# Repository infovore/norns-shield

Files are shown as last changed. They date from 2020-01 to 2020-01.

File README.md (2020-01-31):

# norns-shield



minimal/tiny open-source/DIY shield for Raspberry Pi boards, providing hardware compatibility with the [norns](monome.org/norns) ecosystem.

- audio codec: CS4720
- audio jacks: 3.5mm stereo in/out, line level
- OLED: NHD-2.7-12864WDW3
- 3x pushbuttons, 3x rotary encoders

see the full [BOM on Octopart](https://octopart.com/bom-tool/Q3rQej3x)

see [https://llllllll.co/t/diy-norns-shield](https://llllllll.co/t/diy-norns-shield/27638) for discussion.

[monome.org](https://monome.org)

SMD-populated PCB available from [monome.org](https://market.monome.org)

**200131 update:** tip/ring on audio IO are now swapped around. This will make
left/right work as per the default, out of the box Norns image.

If you are using an older shield than 200131, and want to reverse the audio routing
such that panning works correctly, place an empty file called `reverse.txt` in the
home directory on your norns. (Eg: SSH into norns, and type `touch
reverse.txt`). Restart the norns engines from the UI, and you should have
correct routing.





## assembly

for SMD-populated circuit.

parts shown (header already soldered to OLED)



first solder the OLED header. then the encoders, and keys.





then attach the pi header to the other side and solder as shown.



attach the screen to the top.

check the forum thread above for the newest disk image.

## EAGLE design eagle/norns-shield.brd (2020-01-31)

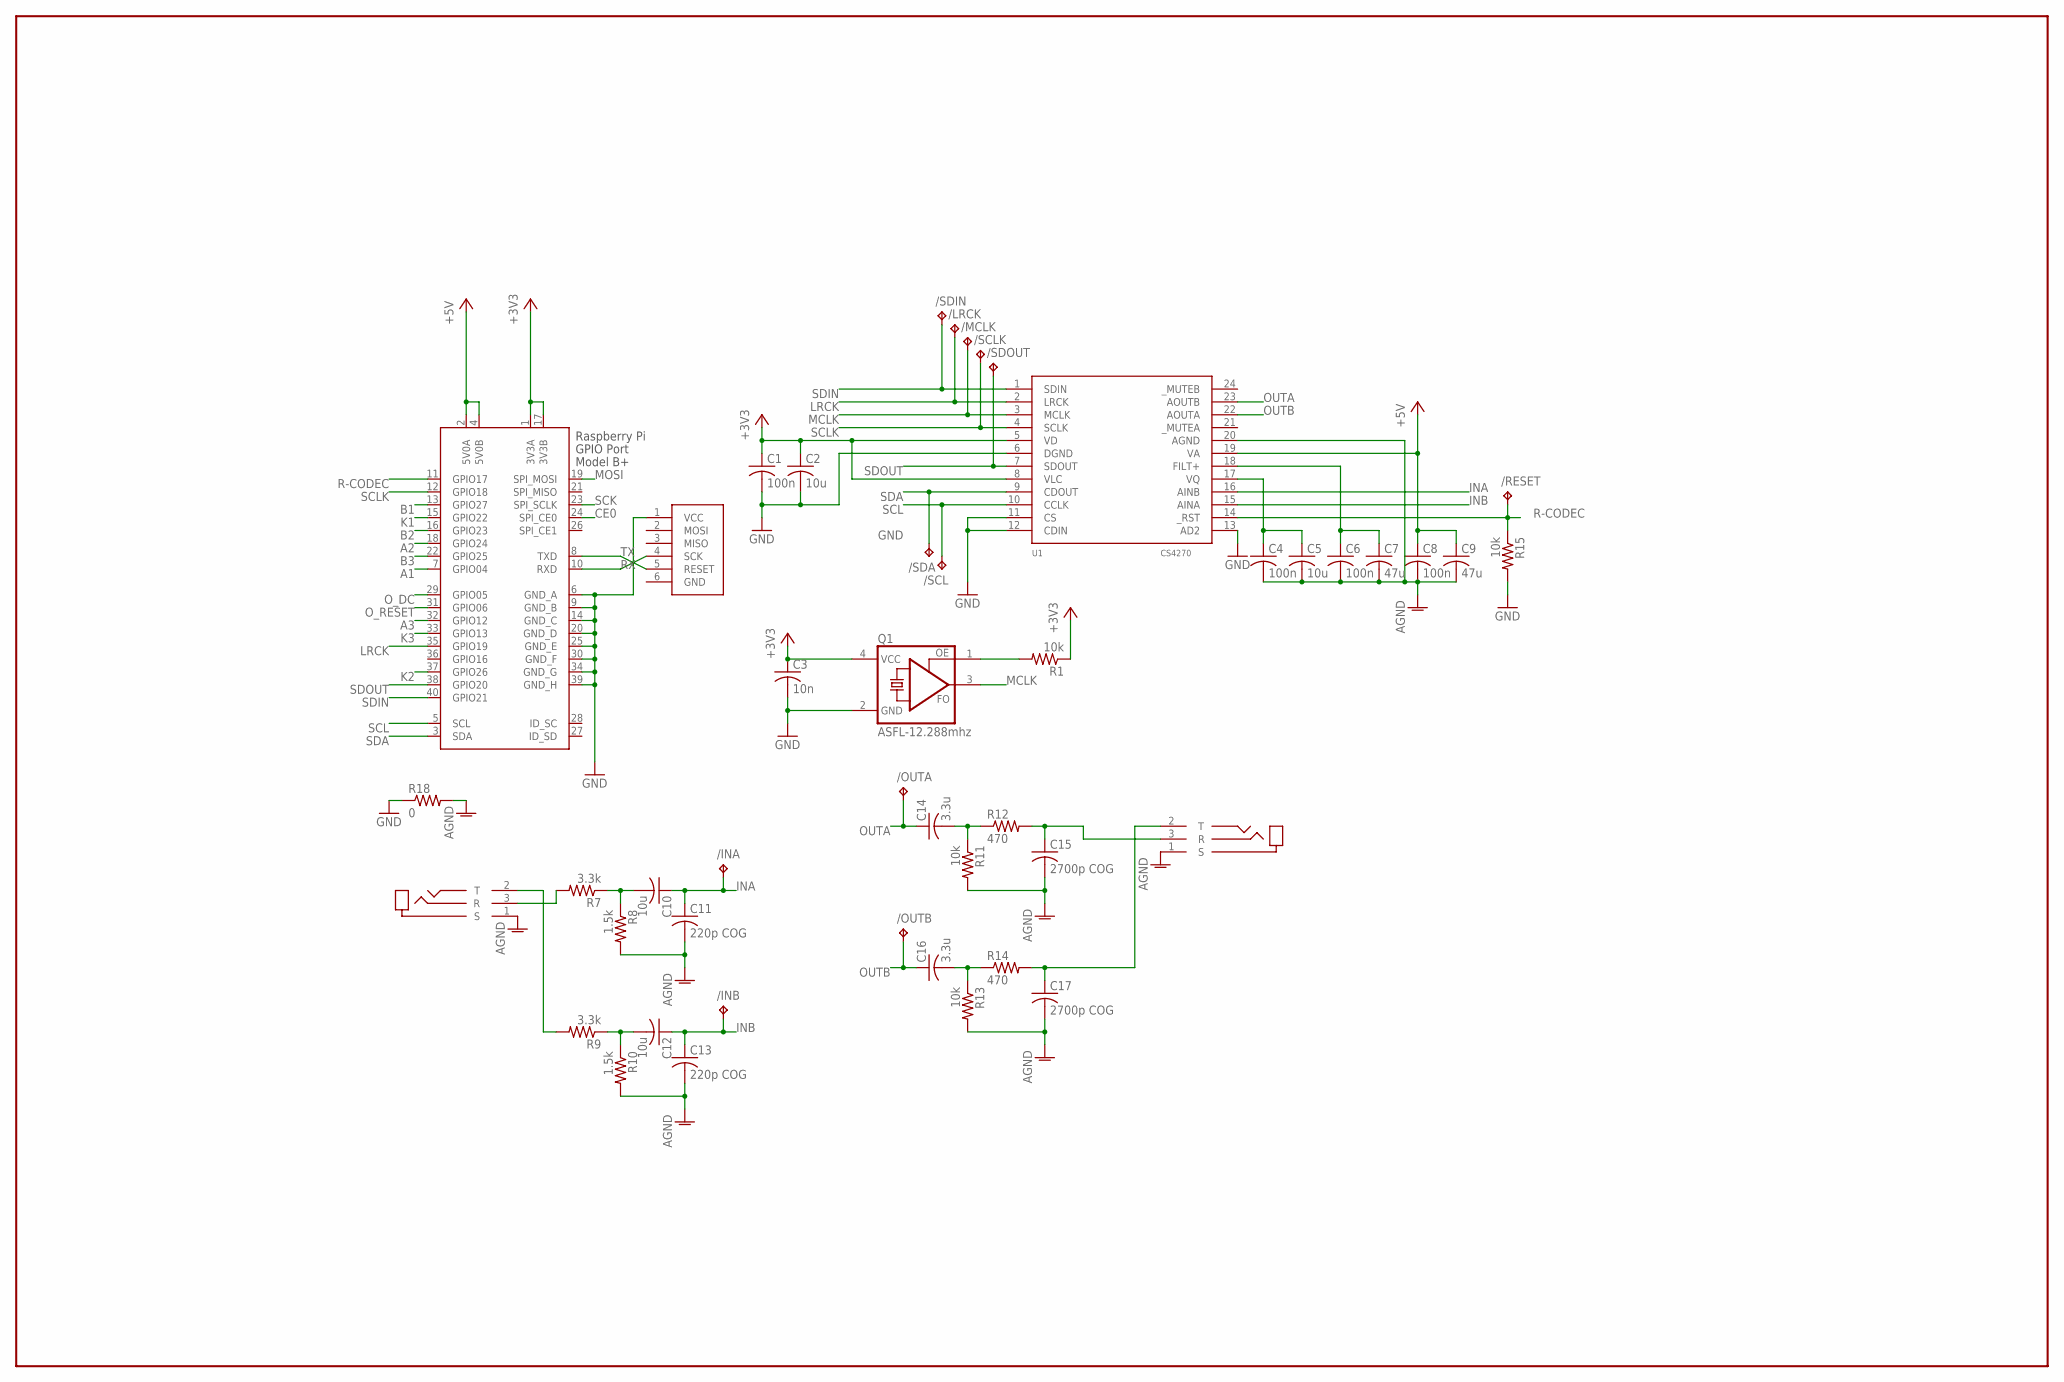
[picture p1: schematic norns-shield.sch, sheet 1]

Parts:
/INA: TPTP12R; TP12R
/INB: TPTP12R; TP12R
/LRCK: TPTP12R; TP12R
/MCLK: TPTP12R; TP12R
/OUTA: TPTP12R; TP12R
/OUTB: TPTP12R; TP12R
/RESET: TPTP12R; TP12R
/SCL: TPTP12R; TP12R
/SCLK: TPTP12R; TP12R
/SDA: TPTP12R; TP12R
/SDIN: TPTP12R; TP12R
/SDOUT: TPTP12R; TP12R
C1, C4, C6, C8: 100n; C0603
C2, C5, C10, C12: 10u; C0805
C3: 10n; C0603
C7, C9: 47u; C1206
C11, C13: 220p COG; C0603
C14, C16: 3.3u; C0805
C15, C17: 2700p COG; C0603
J1: TRS-IN; SJ-3523-SMT
J2: TRS-OUT; SJ-3523-SMT
J3: ISP-ROW
Q1: ASFL-12.288mhz; ASF
R1, R11, R13, R15: 10k; R0603
R7, R9: 3.3k; R0603
R8, R10: 1.5k; R0603
R12, R14: 470; R0603
R18: 0; R0603
U1: CS4270; TSSOP24
X1: RASPI_BOARD_B+#_E3; RASPI_BOARD_B+_EDGES_3DRILL

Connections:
+3V3: C1.1, C2.1, C3.1, Q1.4 (VCC), R1.1, U1.5 (VD), U1.8 (VLC), X1.1 (3V3A), X1.17 (3V3B); also elsewhere on the board
+5V: C8.1, C9.1, U1.19 (VA), X1.2 (5V0A), X1.4 (5V0B)
A1: X1.7 (GPIO04); also elsewhere on the board
A2: X1.18 (GPIO24); also elsewhere on the board
A3: X1.32 (GPIO12); also elsewhere on the board
AGND: C4.2, C5.2, C6.2, C7.2, C8.2, C9.2, C11.2, C13.2, C15.2, C17.2, J1.1 (S), J2.1 (S), R8.2, R10.2, R11.2, R13.2, R18.2, U1.20 (AGND)
B1: X1.13 (GPIO27); also elsewhere on the board
B2: X1.16 (GPIO23); also elsewhere on the board
B3: X1.22 (GPIO25); also elsewhere on the board
CE0: X1.24 (SPI_CE0); also elsewhere on the board
GND: C1.2, C2.2, C3.2, J3.1 (VCC), Q1.2 (GND), R15.2, R18.1, U1.6 (DGND), U1.11 (CS), U1.12 (CDIN), U1.13 (AD2), X1.6 (GND_A), X1.9 (GND_B), X1.14 (GND_C), X1.20 (GND_D), X1.25 (GND_E), X1.30 (GND_F), X1.34 (GND_G), X1.39 (GND_H); also elsewhere on the board
INA: /INA.TP, C10.1, C11.1, U1.16 (AINB)
INB: /INB.TP, C12.1, C13.1, U1.15 (AINA)
K1: X1.15 (GPIO22); also elsewhere on the board
K2: X1.37 (GPIO26); also elsewhere on the board
K3: X1.33 (GPIO13); also elsewhere on the board
LRCK: /LRCK.TP, U1.2 (LRCK), X1.35 (GPIO19)
MCLK: /MCLK.TP, Q1.3 (FO), U1.3 (MCLK)
MOSI: X1.19 (SPI_MOSI); also elsewhere on the board
unnamed: Q1.1 (OE), R1.2
unnamed: C4.1, C5.1, U1.17 (VQ)
unnamed: C6.1, C7.1, U1.18 (FILT+)
unnamed: J1.2 (T), R9.2
unnamed: J1.3 (R), R7.2
unnamed: C10.2, R7.1, R8.1
unnamed: C12.2, R9.1, R10.1
unnamed: C16.2, R13.1, R14.1
unnamed: C14.2, R11.1, R12.1
unnamed: C15.1, J2.3 (R), R12.2
unnamed: C17.1, J2.2 (T), R14.2
OUTA: /OUTA.TP, C14.1, U1.23 (AOUTB)
OUTB: /OUTB.TP, C16.1, U1.22 (AOUTA)
O_DC: X1.29 (GPIO05); also elsewhere on the board
O_RESET: X1.31 (GPIO06); also elsewhere on the board
R-CODEC: /RESET.TP, R15.1, U1.14 (_RST), X1.11 (GPIO17)
RX: J3.4 (SCK), X1.10 (RXD)
SCK: X1.23 (SPI_SCLK); also elsewhere on the board
SCL: /SCL.TP, U1.10 (CCLK), X1.5 (SCL)
SCLK: /SCLK.TP, U1.4 (SCLK), X1.12 (GPIO18)
SDA: /SDA.TP, U1.9 (CDOUT), X1.3 (SDA)
SDIN: /SDIN.TP, U1.1 (SDIN), X1.40 (GPIO21)
SDOUT: /SDOUT.TP, U1.7 (SDOUT), X1.38 (GPIO20)
TX: J3.5 (RESET), X1.8 (TXD)

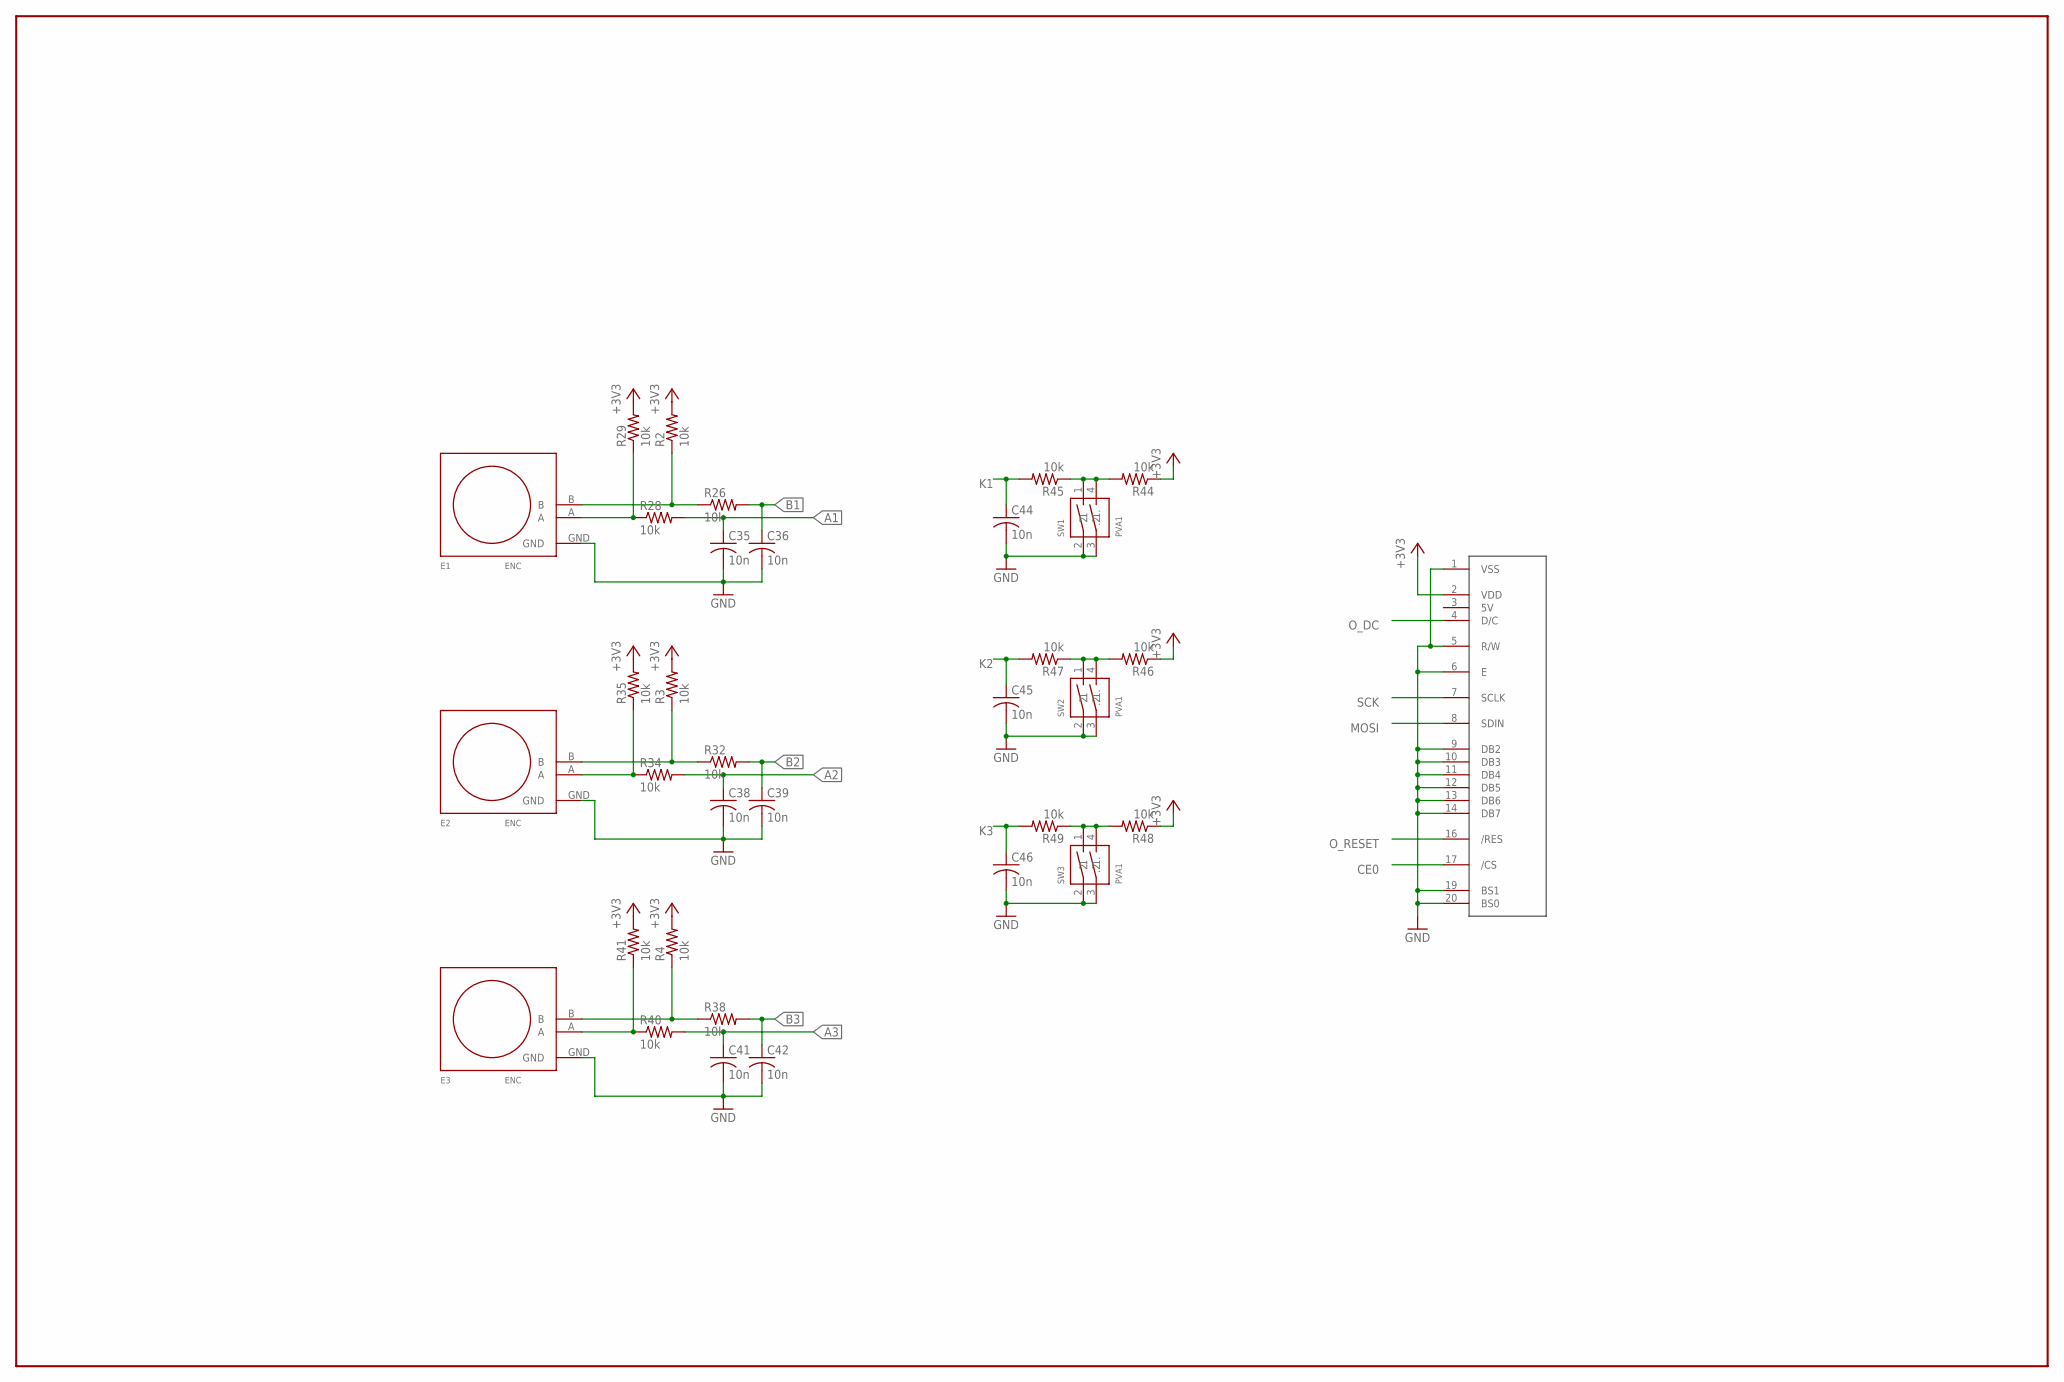
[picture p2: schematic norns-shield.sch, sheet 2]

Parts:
C35, C36, C38, C39, C41, C42, C44, C45, C46: 10n; C0603
E1, E2, E3: ENC; PEC11RN
R2, R3, R4, R26, R28, R29, R32, R34, R35, R38, R40, R41, R44, R45, R46, R47, R48, R49: 10k; R0603
SW1, SW2, SW3: PVA1
U$1: OLED128X64; OLED-ALEPH

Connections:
+3V3: R2.2, R3.2, R4.2, R29.2, R35.2, R41.2, R44.1, R46.1, R48.1, U$1.2 (VDD); also elsewhere on the board
A1: C35.1, R28.2; also elsewhere on the board
A2: C38.1, R34.2; also elsewhere on the board
A3: C41.1, R40.2; also elsewhere on the board
B1: C36.1, R26.2; also elsewhere on the board
B2: C39.1, R32.2; also elsewhere on the board
B3: C42.1, R38.2; also elsewhere on the board
CE0: U$1.17 (/CS); also elsewhere on the board
GND: C35.2, C36.2, C38.2, C39.2, C41.2, C42.2, C44.2, C45.2, C46.2, E1.GND, E2.GND, E3.GND, SW1.2 (1), SW1.3 (1.), SW2.2 (1), SW2.3 (1.), SW3.2 (1), SW3.3 (1.), U$1.1 (VSS), U$1.5 (R/W), U$1.6 (E), U$1.9 (DB2), U$1.10 (DB3), U$1.11 (DB4), U$1.12 (DB5), U$1.13 (DB6), U$1.14 (DB7), U$1.19 (BS1), U$1.20 (BS0); also elsewhere on the board
K1: C44.1, R45.2; also elsewhere on the board
K2: C45.1, R47.2; also elsewhere on the board
K3: C46.1, R49.2; also elsewhere on the board
MOSI: U$1.8 (SDIN); also elsewhere on the board
unnamed: R44.2, R45.1, SW1.1 (2), SW1.4 (.2)
unnamed: R46.2, R47.1, SW2.1 (2), SW2.4 (.2)
unnamed: R48.2, R49.1, SW3.1 (2), SW3.4 (.2)
unnamed: E1.A, R28.1, R29.1
unnamed: E1.B, R2.1, R26.1
unnamed: E2.B, R3.1, R32.1
unnamed: E2.A, R34.1, R35.1
unnamed: E3.B, R4.1, R38.1
unnamed: E3.A, R40.1, R41.1
O_DC: U$1.4 (D/C); also elsewhere on the board
O_RESET: U$1.16 (/RES); also elsewhere on the board
SCK: U$1.7 (SCLK); also elsewhere on the board

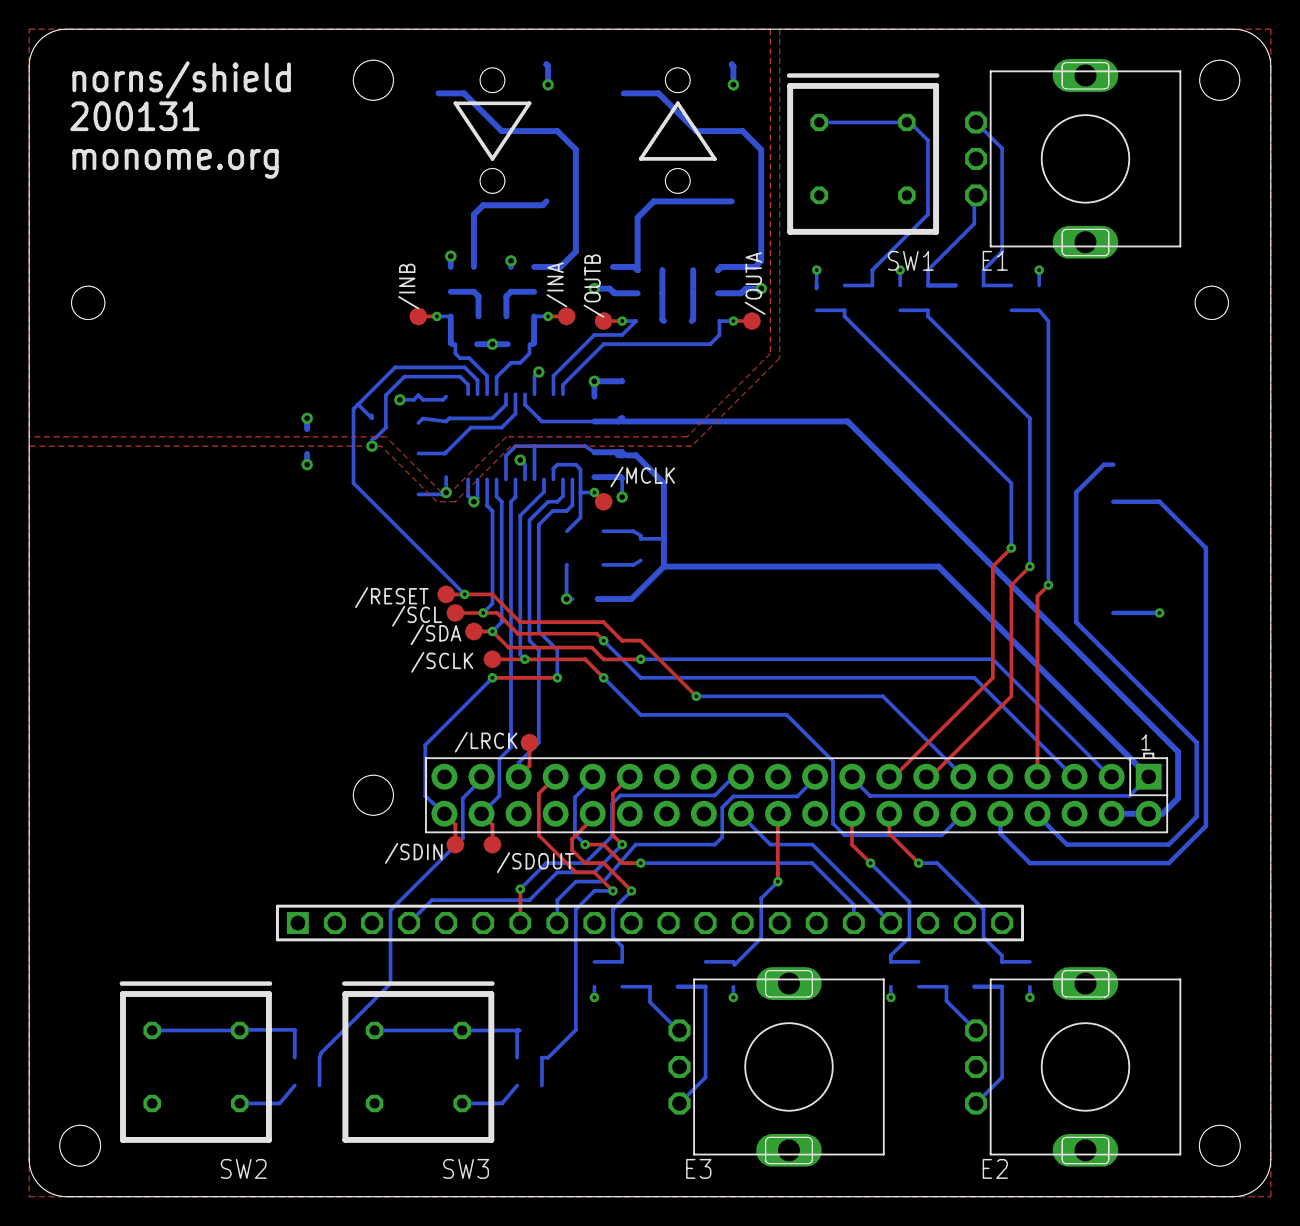
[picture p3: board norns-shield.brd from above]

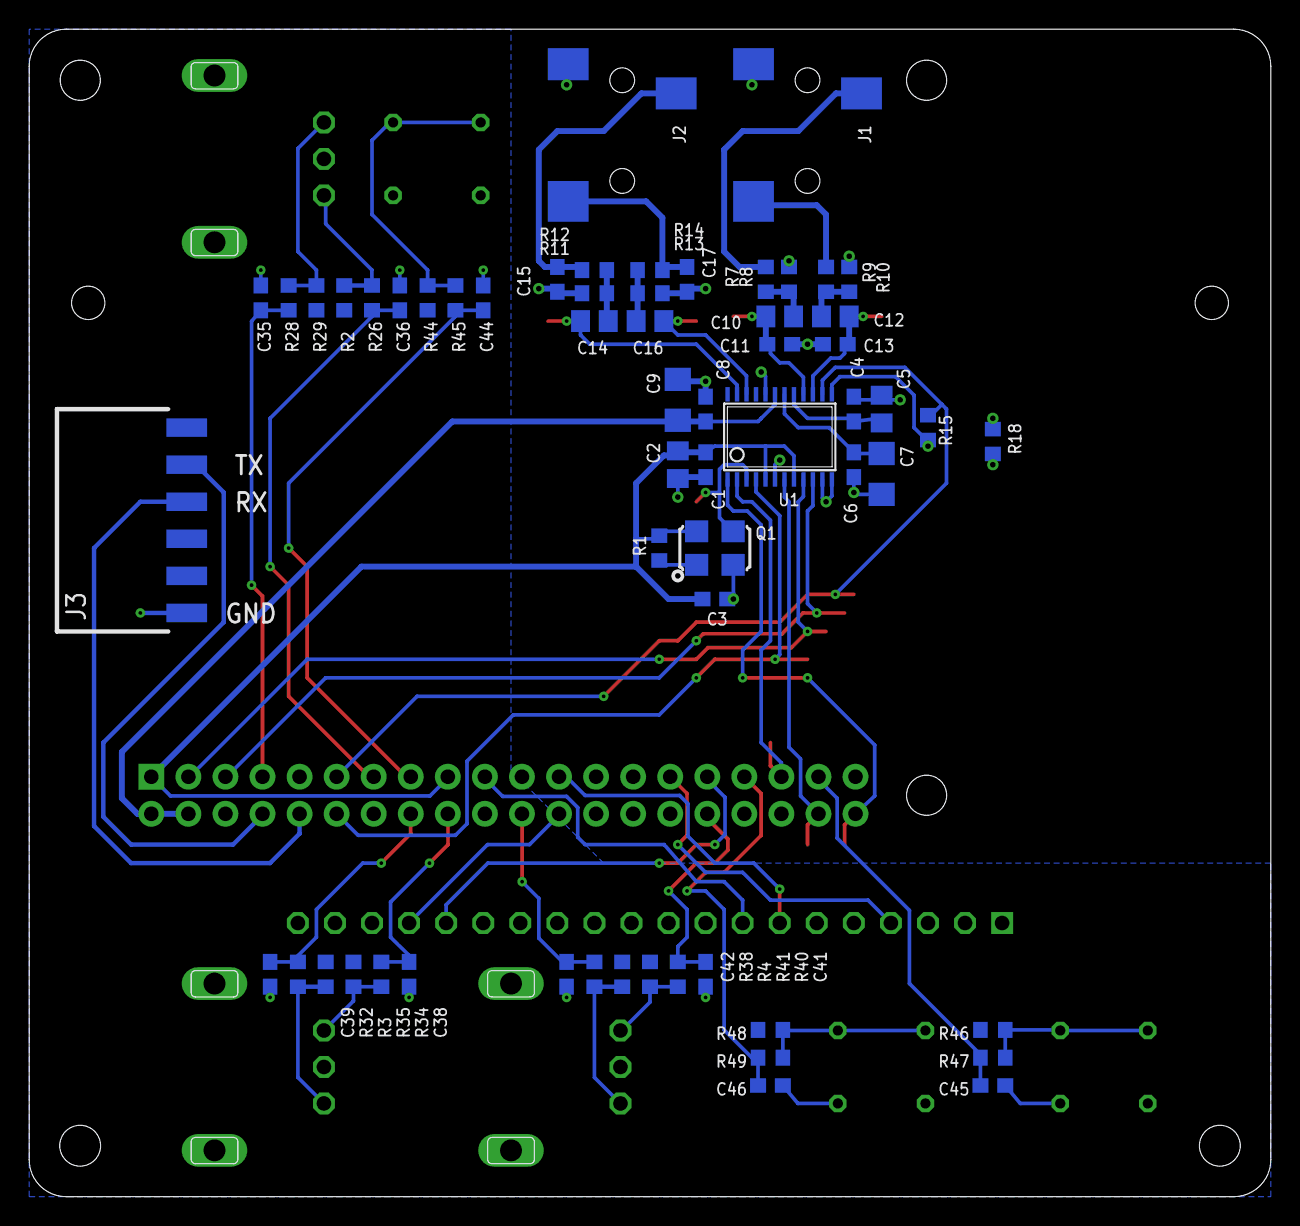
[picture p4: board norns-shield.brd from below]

Board: 2 copper layers, 85.1 x 80.0 mm, 80 parts (60 on the bottom side), 52 nets.
